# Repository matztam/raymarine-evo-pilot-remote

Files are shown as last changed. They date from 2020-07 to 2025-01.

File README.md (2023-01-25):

# Remote for Raymarine Evolution Autopilots

<table>
<tbody>
  <tr>
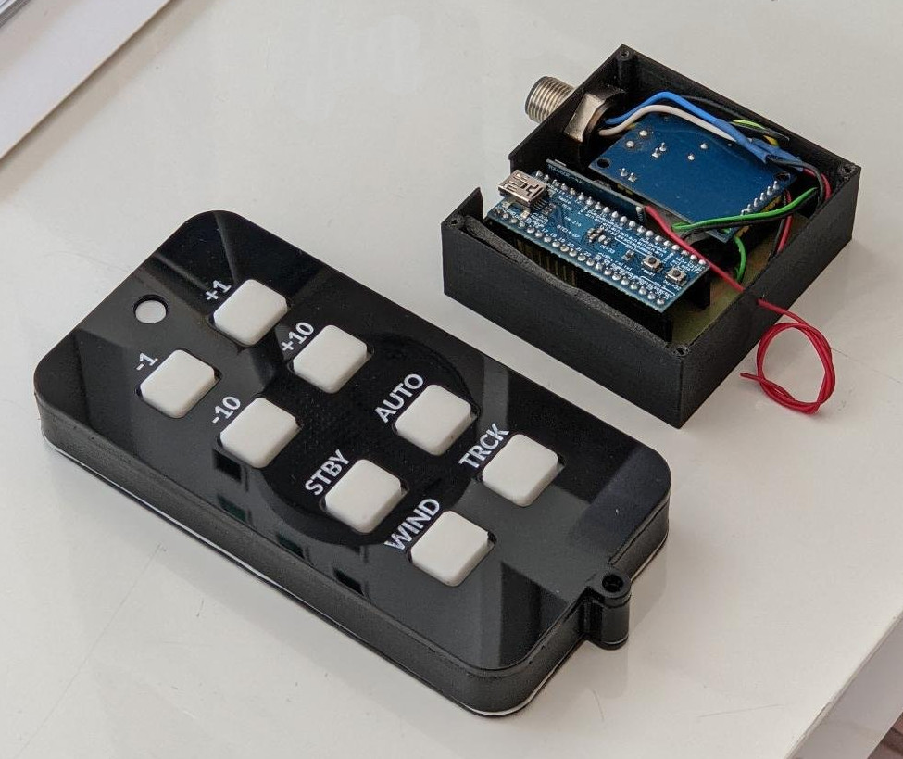
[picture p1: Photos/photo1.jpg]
    <td rowspan="2" valign="top"></td>
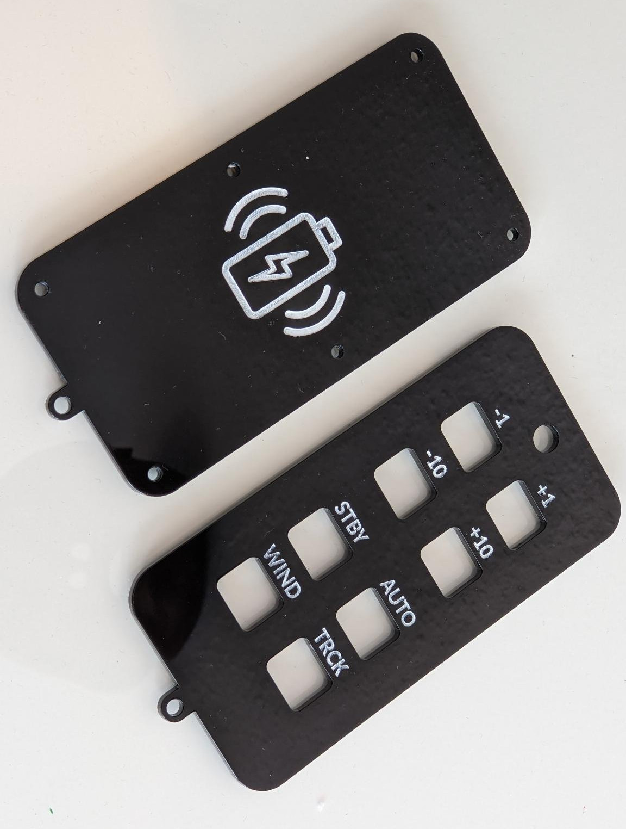
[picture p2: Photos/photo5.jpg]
    <td valign="top"></td>
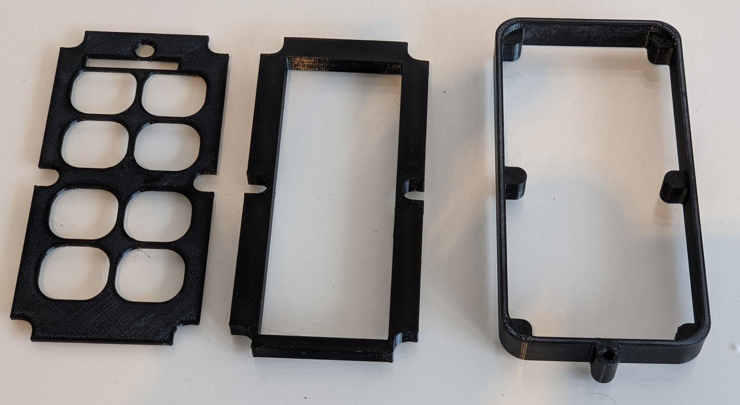
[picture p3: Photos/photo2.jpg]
    <td valign="bottom"></td>
  </tr>
  <tr>
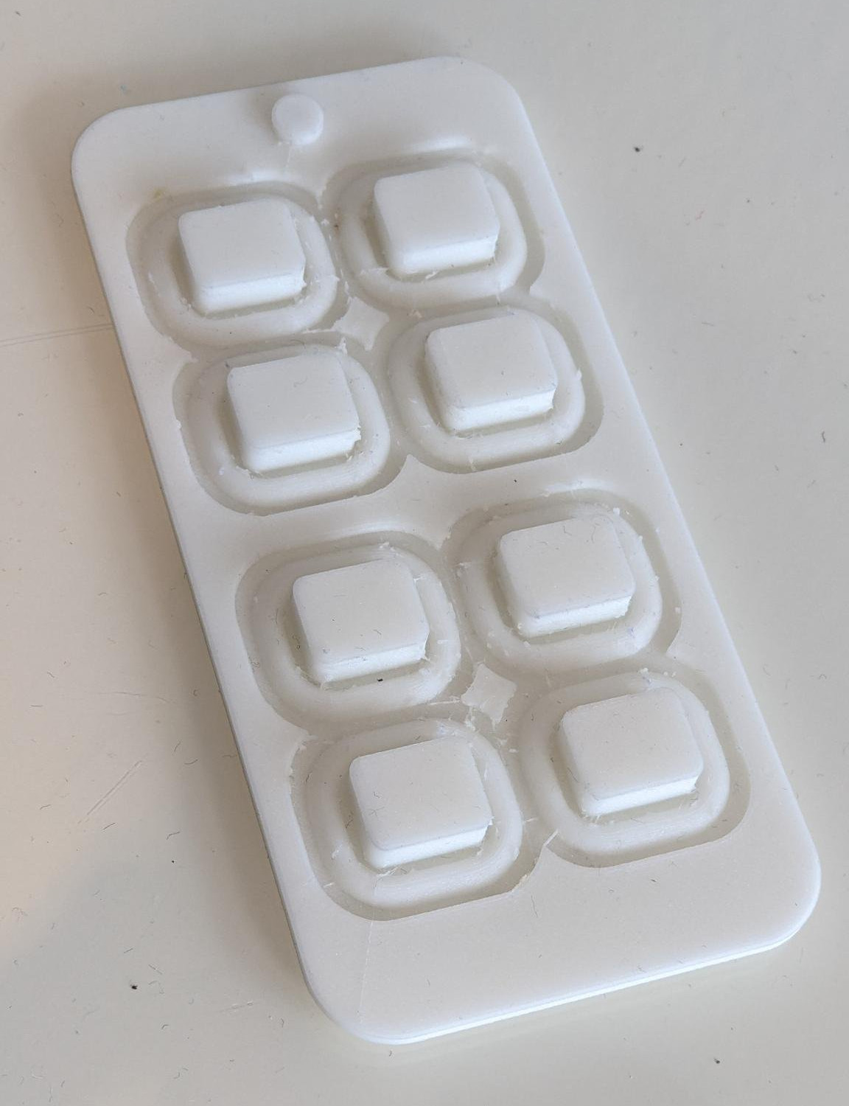
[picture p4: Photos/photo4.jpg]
    <td valign="top"></td>
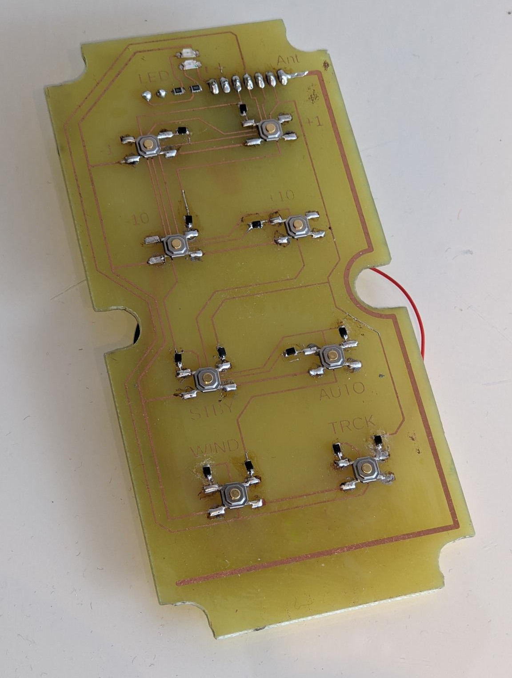
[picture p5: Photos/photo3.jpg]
    <td valign="top"></td>
  </tr>
</tbody>
</table>

## Libraries used:
* https://github.com/ttlappalainen/NMEA2000
* https://github.com/ttlappalainen/NMEA2000_mcp
* https://github.com/Seeed-Studio/CAN_BUS_Shield
* https://github.com/rogerclarkmelbourne/Arduino_STM32

## Hardware:

### Receiver
* Maple Mini (STM32F103) / Arduino_STM32
* MCP2551 CAN-BUS Module
* Logic Level Converter (https://www.sparkfun.com/products/12009)
* QIACHIP RX480E 433Mhz 4CH RF Receiver (https://qiachip.com/collections/all-products-1/products/qiachip-tx118sa-4-rx480e-kit-433-92mhz-wireless-wide-voltage-coding-transmitter-module-and-decoding-receiver-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)
* 12V to 5V step down converter

### Remote / Sender
* Qiachip TX118SA 433Mhz 4CH RF Transmitter (https://qiachip.com/collections/all-products-1/products/qiachip-tx118sa-4-rx480e-kit-433-92mhz-wireless-wide-voltage-coding-transmitter-module-and-decoding-receiver-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)
* Qi wireless charging receiver coil (https://www.aliexpress.com/item/32966646423.html)
* Lipo charger module
* Lipo battery 3.7V
* (Any Qi compatible charger)

### 3D print
keypad and seal were printed using TPE. The front and back were laser cut of acrylic (thanks to [@jliebers](https://github.com/jliebers)!). The remaining parts were printed using PETG. The front was glued to the frame using T7000

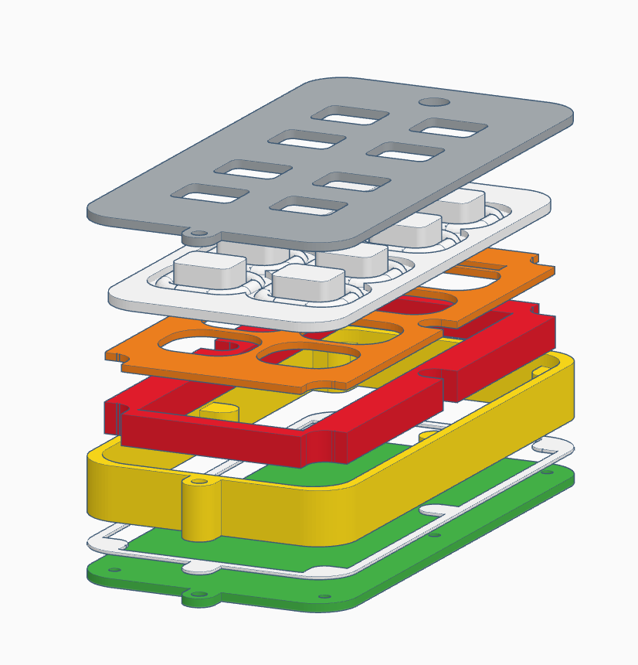
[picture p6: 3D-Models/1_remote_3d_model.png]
3d model


## Remote shortcuts

| Keys | Press and hold for one seconds | Description |
|---|---|---|
| +1 & +10 | 1 | Tack starboard |
| -1 & -10 | 1 | Tack portside |
| +1 & Wind | 1 | Key lock |
| Standby & Auto | 2 | Set target wind angle to 0° |

## Commands via tty
| input | Description |
| ----- | --- |
| s | Standby |
| a | Auto (course) mode |
| w | Wind Vane mode |
| t | Track mode |
| + | Plus 10 degrees |
| - | Minus 10 degrees |
| c | Confirm Waypoint advance |
| 1 | Key +1 |
| 2 | Key +10 |
| 3 | Key -1 |
| 4 | Key -10 |
| 5 | Keys -1 and -10 pressed simultaneously |
| 6 | Keys +1 and +10 pressed simultaneously |

## Board

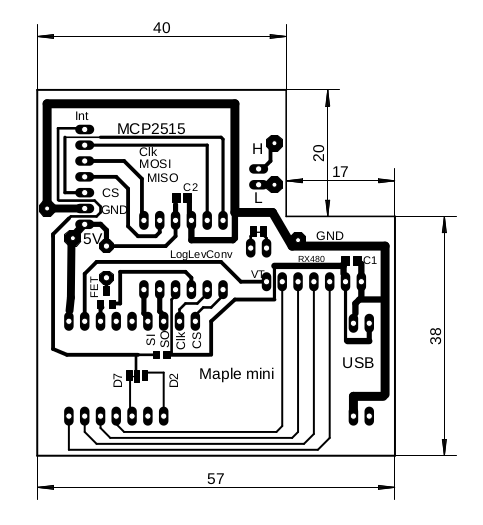
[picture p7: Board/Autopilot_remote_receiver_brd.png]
board receiver

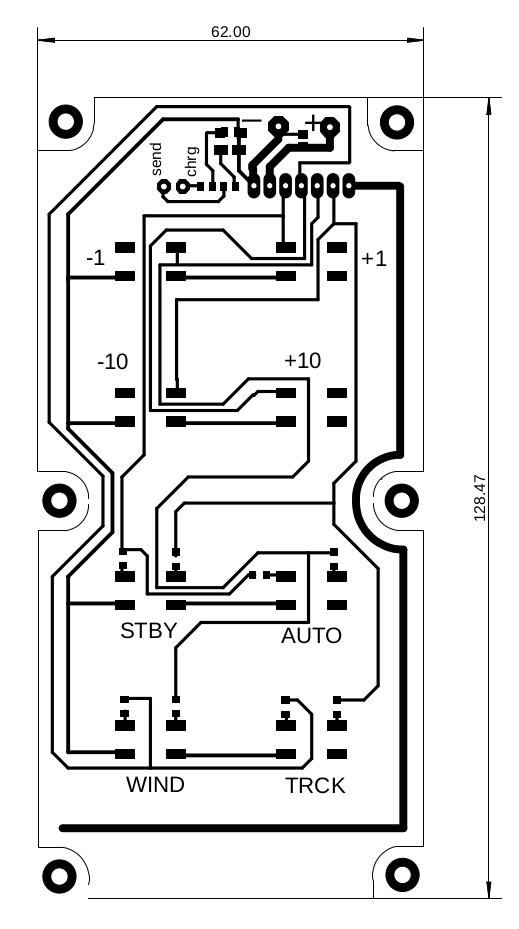
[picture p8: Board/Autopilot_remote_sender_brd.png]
board sender


## Schematic

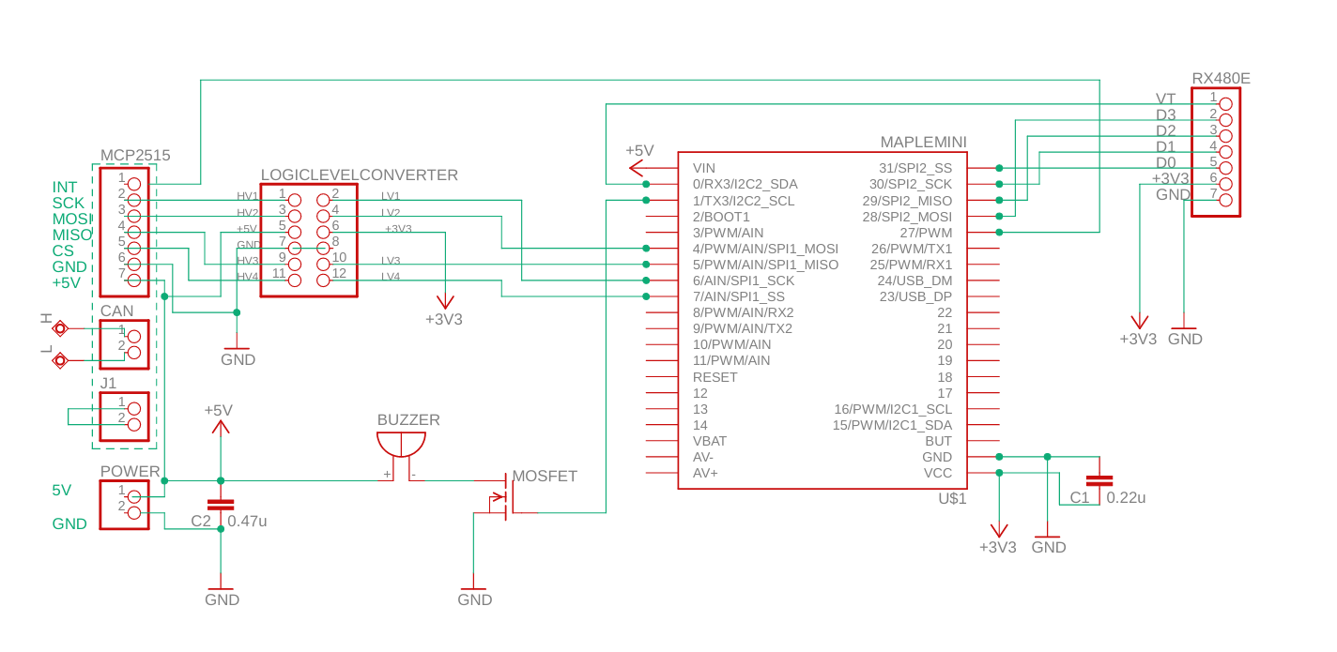
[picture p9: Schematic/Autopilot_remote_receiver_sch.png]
schematic receiver

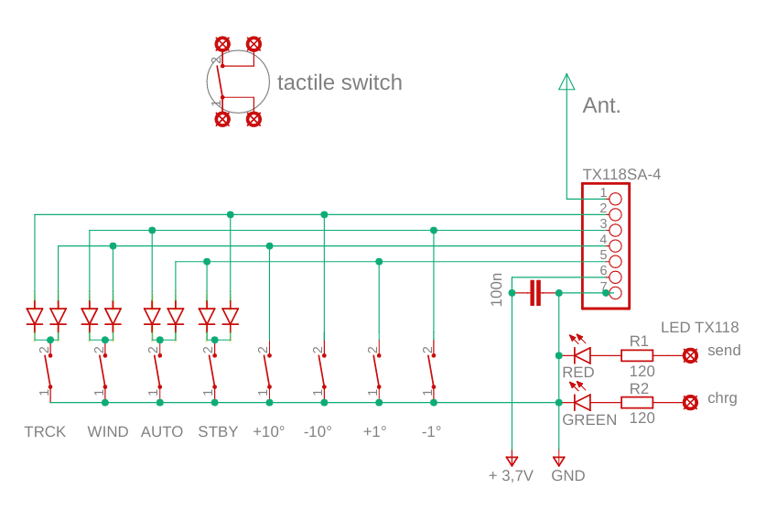
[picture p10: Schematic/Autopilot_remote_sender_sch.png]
schematic sender


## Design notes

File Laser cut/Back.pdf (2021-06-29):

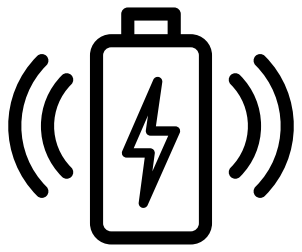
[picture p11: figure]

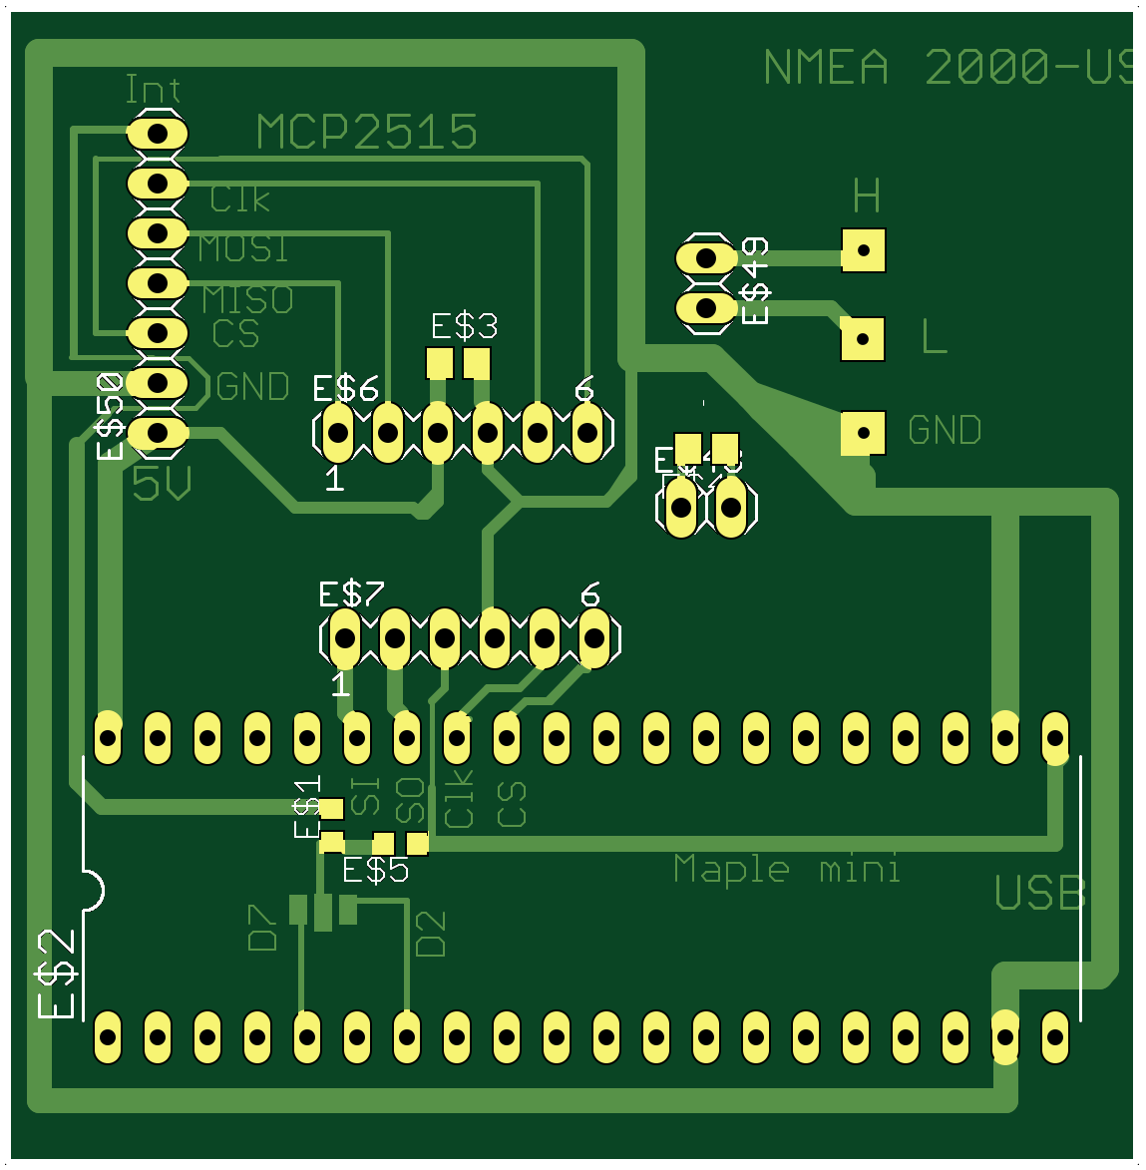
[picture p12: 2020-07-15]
Board/NMEA2000_USB_topview.png

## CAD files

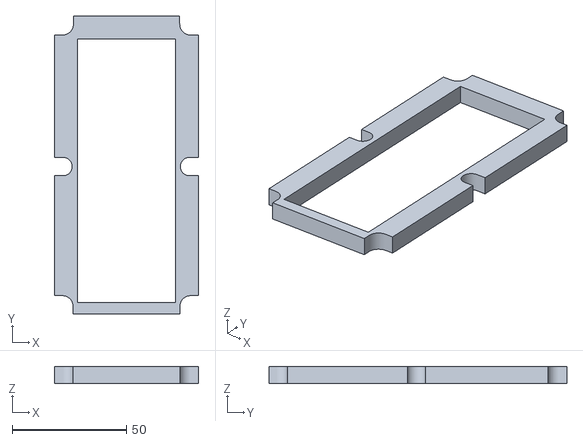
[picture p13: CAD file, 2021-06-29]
3D-Models/Inner frame.stl
63.0 x 130.2 x 7.50

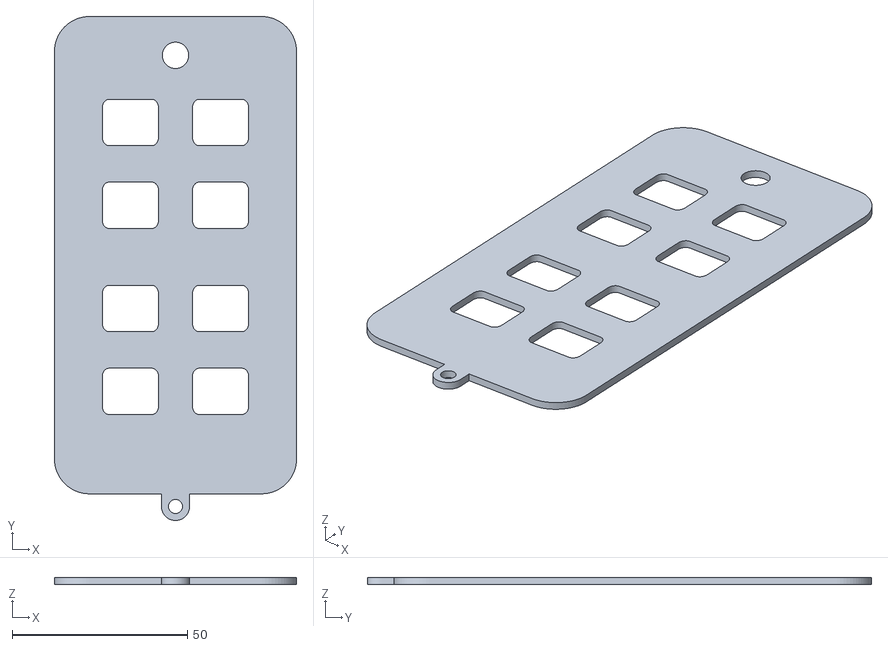
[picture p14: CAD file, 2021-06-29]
3D-Models/Front.stl
69.0 x 143.6 x 2.00

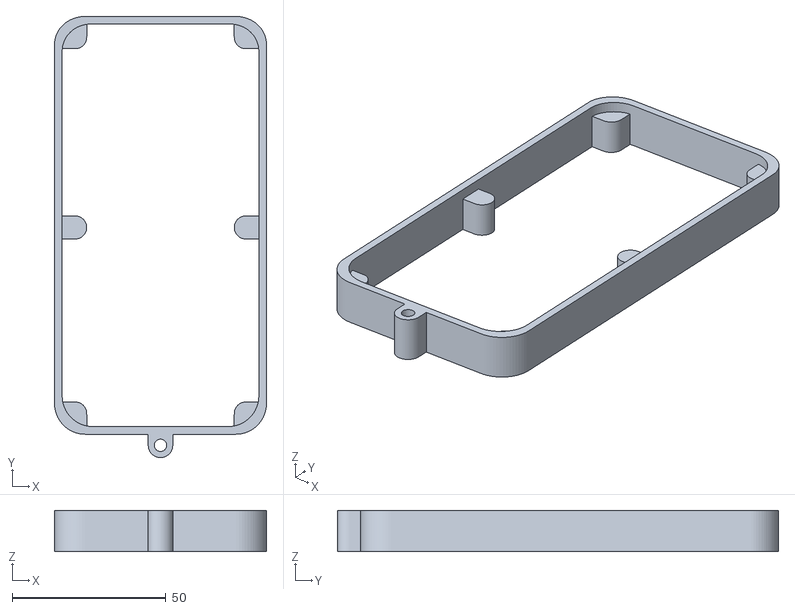
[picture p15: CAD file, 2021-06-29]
3D-Models/Outer frame.stl
69.0 x 143.6 x 13.5

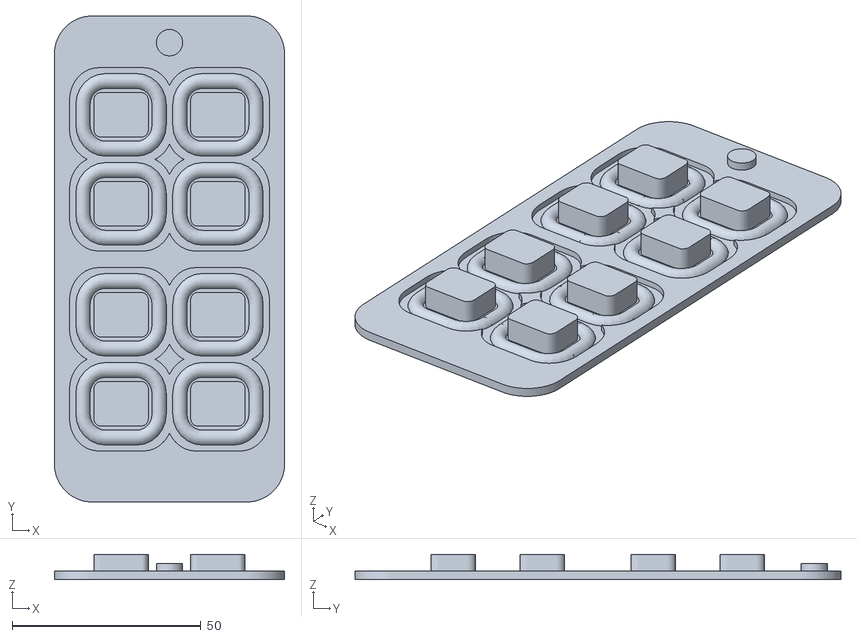
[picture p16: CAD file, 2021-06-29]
3D-Models/Key pad.stl
61.0 x 128.8 x 6.72

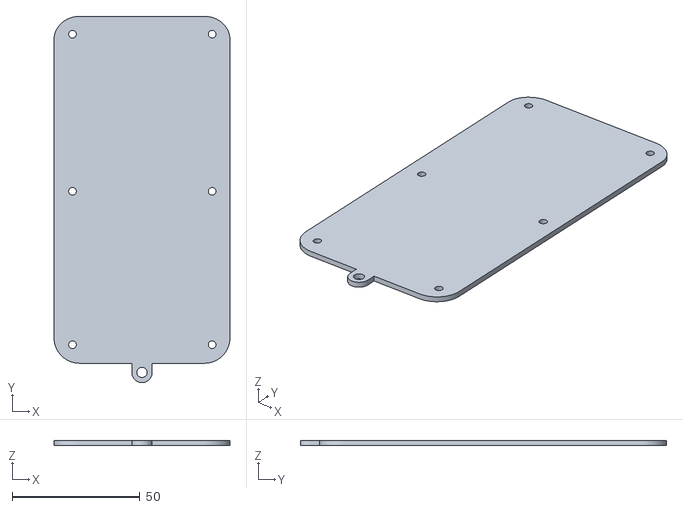
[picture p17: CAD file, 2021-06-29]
3D-Models/Back.stl
69.0 x 143.6 x 2.00

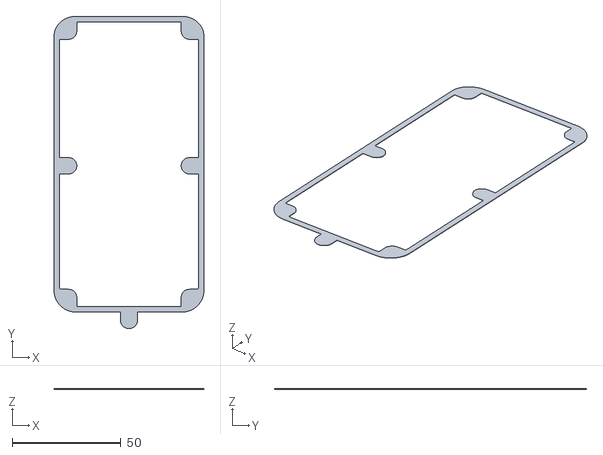
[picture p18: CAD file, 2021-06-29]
3D-Models/Seal.stl
69.0 x 143.6 x 0.5

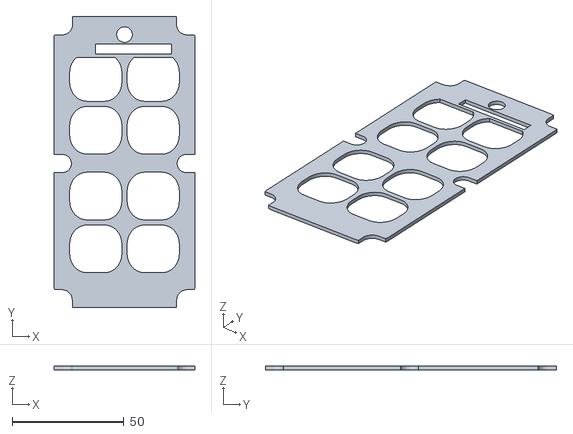
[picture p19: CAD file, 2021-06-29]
3D-Models/Placeholder.stl
63.0 x 130.2 x 1.60

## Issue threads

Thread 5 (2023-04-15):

Gerber

m-feddersen, 2023-04-15:
Hello Matztam,
I fail to create the Gerber file. I can't do that with Fusion 360 and Kicad. Can you add the finished Gerber file to your package, or give me a tip how to create it from the schematic?
With kind regards
Matze

matztam, 2025-01-13:
Hi Matze,
Sorry, it took a while. Here are the Gerber files:: https://github.com/matztam/raymarine-evo-pilot-remote/tree/master/Board/Gerber

Closed 2025-01-13.

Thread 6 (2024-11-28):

EvoPilotremote.ino.elf section `.text' will not fit in region `FLASH'

syntacrsc, 2024-11-28:
Hello.

While trying to verify the .ino code I get the error below - looks like the "Genric STM32F1" series board does not have enough space for the build?

I've already tried to disable some of the HAL Modules via hal_conf_extra.h
```
#define HAL_ADC_MODULE_DISABLED
#define HAL_I2C_MODULE_DISABLED
#define HAL_RTC_MODULE_DISABLED
//#define HAL_SPI_MODULE_DISABLED
#define HAL_TIM_MODULE_DISABLED
```
This reduced the size a little but not enough to fit.

Just for curiousity sake I tried "Genric STM32F2 series" board - that compiles correctly (but I'm not sure what will happen when I'd try to flush to a STM32F1 series board).

My IDE ist Arduino IDE 2.3.3.

What am I doing wrong?

Any help is highly appreciated!

Thanks and kind regards,
Ralph...

P.S.:
This is the error message I'm getting:

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

matztam, 2025-01-09:
Please select the board "Maple Mini"

Closed 2025-01-13.

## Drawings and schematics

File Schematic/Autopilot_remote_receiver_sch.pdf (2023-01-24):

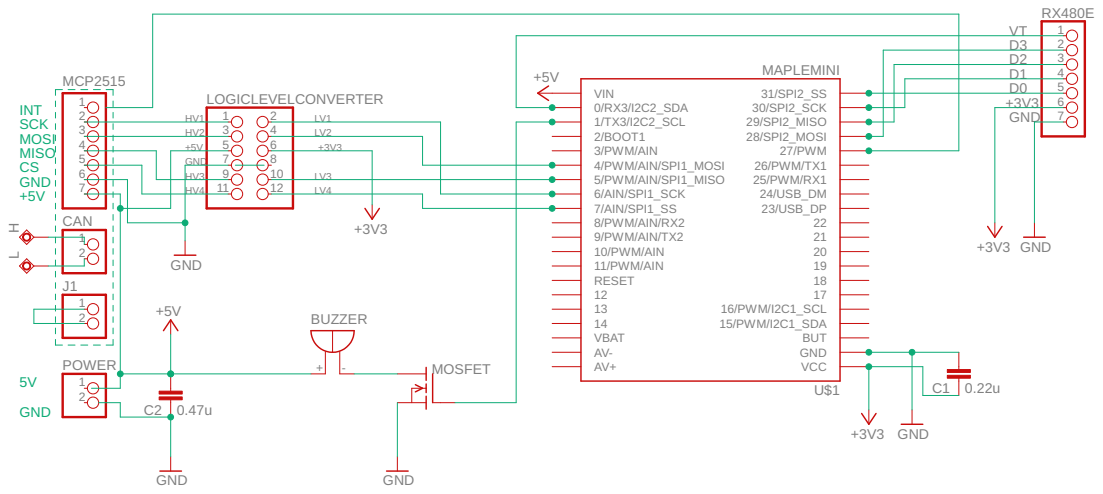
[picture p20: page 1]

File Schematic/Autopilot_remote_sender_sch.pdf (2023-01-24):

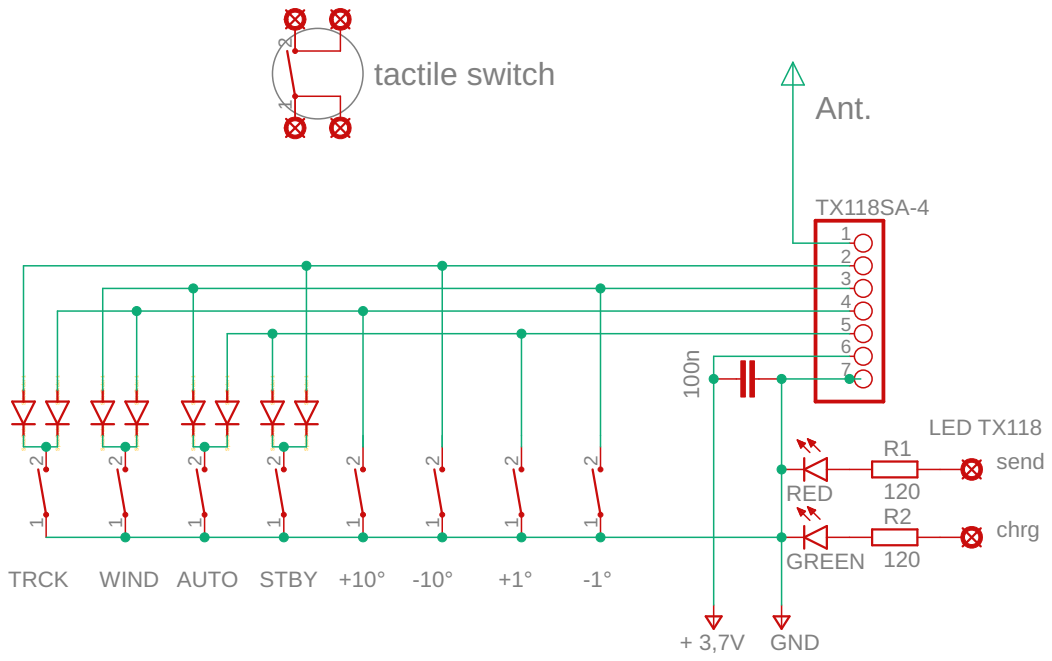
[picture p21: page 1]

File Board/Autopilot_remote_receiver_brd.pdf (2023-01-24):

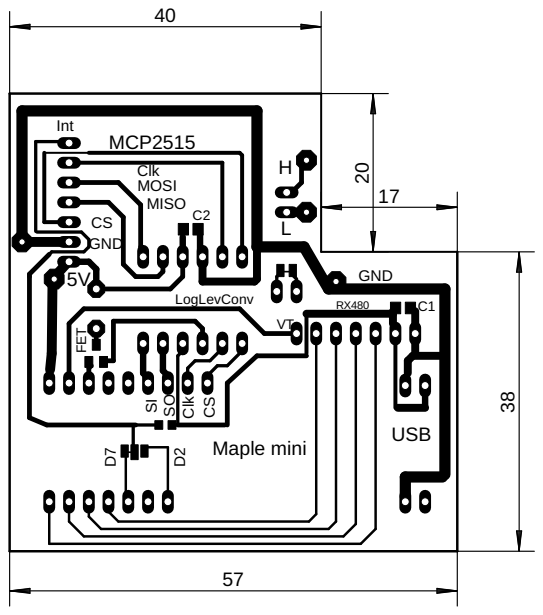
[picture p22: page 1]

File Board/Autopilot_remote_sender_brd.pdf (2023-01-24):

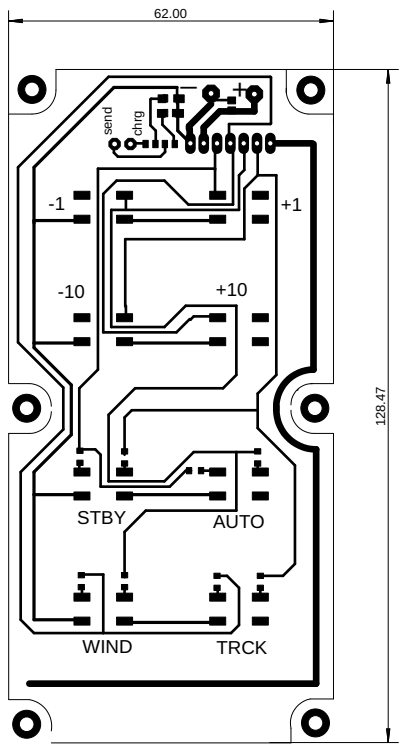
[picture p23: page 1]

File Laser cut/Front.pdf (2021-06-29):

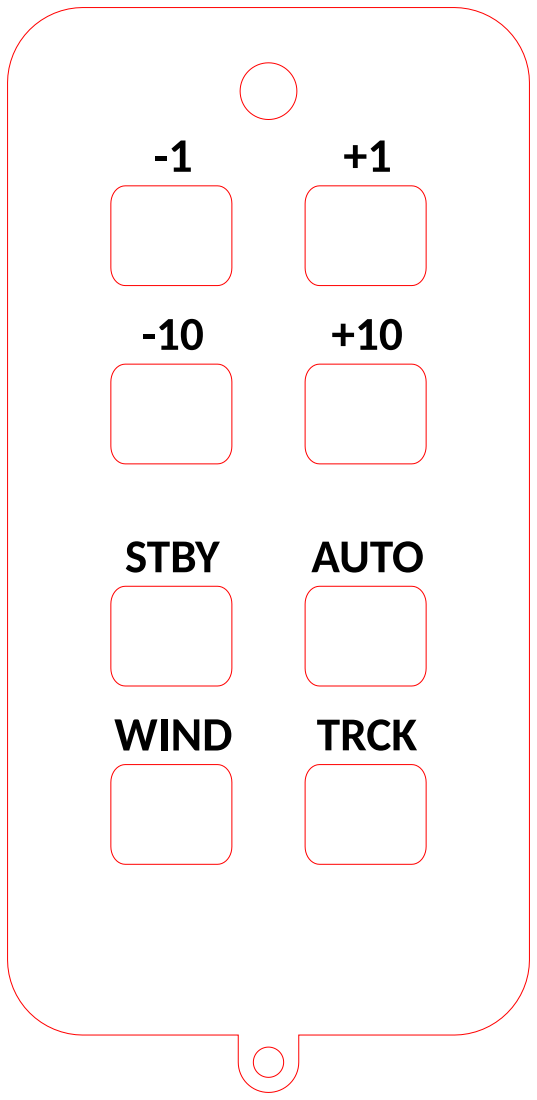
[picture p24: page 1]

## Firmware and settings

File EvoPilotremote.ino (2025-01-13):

#define DEBUG

#ifdef DEBUG
#define DEBUG_PRINT(x) Serial.print(x)
#define DEBUG_PRINTLN(x) Serial.println(x)
#define DEBUG_PRINTLNFMT(x,y) Serial.println(x,y)
#else
#define DEBUG_PRINT(x)
#define DEBUG_PRINTLN(x)
#define DEBUG_PRINTLNFMT(x,y)
#endif

#define KEYLOCK_TIMEOUT_MS 1000
#define TACK_TIMEOUT_MS 1000
#define HEADING_WIND_TIMEOUT_MS 2000

#define INPUT_ADJUST_HEADING_PLUS_1       4   //0100
#define INPUT_ADJUST_HEADING_PLUS_10      8   //1000
#define INPUT_ADJUST_HEADING_MINUS_1      2   //0010
#define INPUT_ADJUST_HEADING_MINUS_10     1   //0001
#define INPUT_ADJUST_HEADING_AGAINST_WIND 7   //0111
#define INPUT_TACK_STARBOARD              12  //1100
#define INPUT_TACK_PORT                   3   //0011
#define INPUT_STATE_AUTO                  6   //0110
#define INPUT_STATE_WIND                  10  //1010
#define INPUT_STATE_STANDBY               5   //0101
#define INPUT_STATE_ROUTE                 9   //1011
#define INPUT_KEYLOCK                     14  //1110

#define pinBuzzer PB10
#define pinVT     PB11
#define pinD0     PB12
#define pinD1     PB13
#define pinD2     PB14
#define pinD3     PB15

#define USE_N2K_CAN 1

#define N2k_SPI_CS_PIN 7
#define N2k_CAN_INT_PIN 27
#define USE_MCP_CAN_CLOCK_SET 8  // possible values 8 for 8Mhz and 16 for 16 Mhz clock

#include <Arduino.h>
#include <N2kMsg.h>
#include <NMEA2000.h>
#include <NMEA2000_CAN.h>

#include "RaymarinePilot.h"
#include "N2kDeviceList.h"
#include <libmaple/iwdg.h>

const unsigned long TransmitMessages[] PROGMEM={126208UL,0};
const unsigned long ReceiveMessages[] PROGMEM={127250L,65288L,65379L,0};

tN2kDeviceList *pN2kDeviceList;

byte inByte;

bool keylockEnabled = true;

long keylockTimeout = 0;
long tackTimeout = 0;
long headingToWindTimeout = 0;
long beepTimeout = 0;

unsigned short* beepPattern;
int beepPatternIndex = 0;

unsigned short BEEP_NULL[] = {0};
unsigned short BEEP_SINGLE_BUTTON[] = {100, 0};
unsigned short BEEP_KEYLOCK_ENABLE[] = {150, 50, 150, 50, 150, 0};
unsigned short BEEP_KEYLOCK_DISABLE[] = {150, 50, 150, 0};
unsigned short BEEP_TACK[] = {1000, 0};
unsigned short BEEP_HEADING_AGAINST_WIND[] = {1000, 200, 1000, 0};
unsigned short BEEP_STARTUP[] = {300, 0};

void setup() {
  iwdg_init(IWDG_PRE_256, 3000); // init an 16+ second wd timer
  pinMode(pinBuzzer, OUTPUT);
  digitalWrite(pinBuzzer, 0);
  pinMode(pinVT, INPUT);
  pinMode(pinD0, INPUT);
  pinMode(pinD1, INPUT);
  pinMode(pinD2, INPUT);
  pinMode(pinD3, INPUT);

  attachInterrupt(digitalPinToInterrupt(pinVT), handleRemoteInput, RISING);

  // Reserve enough buffer for sending all messages. This does not work on small memory devices like Uno or Mega
  NMEA2000.SetN2kCANReceiveFrameBufSize(150);
  NMEA2000.SetN2kCANMsgBufSize(8);
  // Set Product information
  NMEA2000.SetProductInformation("00000001", // Manufacturer's Model serial code
                                 100, // Manufacturer's product code
                                 "Evo Pilot Remote",  // Manufacturer's Model ID
                                 "1.0.0.0",  // Manufacturer's Software version code
                                 "1.0.0.0" // Manufacturer's Model version
                                );
  // Set device information
  NMEA2000.SetDeviceInformation(1111, // Unique number. Use e.g. Serial number.
                                132, // Device function=Analog to NMEA 2000 Gateway. See codes on http://www.nmea.org/Assets/20120726%20nmea%202000%20class%20&%20function%20codes%20v%202.00.pdf
                                25, // Device class=Inter/Intranetwork Device. See codes on  http://www.nmea.org/Assets/20120726%20nmea%202000%20class%20&%20function%20codes%20v%202.00.pdf
                                2046 // Just choosen free from code list on http://www.nmea.org/Assets/20121020%20nmea%202000%20registration%20list.pdf
                               );
  Serial.begin(115200);
  delay(100);

  #ifdef DEBUG
  NMEA2000.SetForwardStream(&Serial);  // PC output on due programming port
  NMEA2000.SetForwardType(tNMEA2000::fwdt_Text); // Show in clear text. Leave uncommented for default Actisense format.
  NMEA2000.SetForwardOwnMessages();
  #endif

  // If you also want to see all traffic on the bus use N2km_ListenAndNode instead of N2km_NodeOnly below
  NMEA2000.SetMode(tNMEA2000::N2km_NodeOnly, 51); //N2km_NodeOnly N2km_ListenAndNode
  NMEA2000.ExtendTransmitMessages(TransmitMessages);
  NMEA2000.ExtendReceiveMessages(ReceiveMessages);

  NMEA2000.SetMsgHandler(RaymarinePilot::HandleNMEA2000Msg);

  
  pN2kDeviceList = new tN2kDeviceList(&NMEA2000);
  #ifdef DEBUG
  NMEA2000.EnableForward(true);
  #endif
  NMEA2000.Open();

  unsigned long t = millis();
  
  while(RaymarinePilot::PilotSourceAddress < 0 && millis() - t < 5000){
    iwdg_feed();
    NMEA2000.ParseMessages();
    RaymarinePilot::PilotSourceAddress = getDeviceSourceAddress("EV-1");
    delay(50);
  }

  if(RaymarinePilot::PilotSourceAddress >= 0){
    Serial.println((String) "Found EV-1 Pilot: " + RaymarinePilot::PilotSourceAddress);
  }else{
    RaymarinePilot::PilotSourceAddress = 204;
    Serial.println((String) "EV-1 Pilot not found. Defaulting to " + RaymarinePilot::PilotSourceAddress);
  }

  beep(BEEP_STARTUP);
  iwdg_init(IWDG_PRE_256, 1250); // set watchdog timer to 8 seconds
}

void loop() {
  iwdg_feed();
  handleTimers();  
  
  if (Serial.available() > 0) {
    inByte = Serial.read();

    if (inByte == 's') {
      Serial.println("Setting PILOT_MODE_STANDBY");
      
      tN2kMsg N2kMsg;
      RaymarinePilot::SetEvoPilotMode(N2kMsg, PILOT_MODE_STANDBY);
      NMEA2000.SendMsg(N2kMsg);
    } 
    
    else if (inByte == 'a') {
      Serial.println("Setting PILOT_MODE_AUTO");
      
      tN2kMsg N2kMsg;
      RaymarinePilot::SetEvoPilotMode(N2kMsg, PILOT_MODE_AUTO);
      NMEA2000.SendMsg(N2kMsg);
    } 
    
    else if (inByte == 'w') {
      Serial.println("Setting PILOT_MODE_WIND");
      
      tN2kMsg N2kMsg;
      RaymarinePilot::SetEvoPilotMode(N2kMsg, PILOT_MODE_WIND);
      NMEA2000.SendMsg(N2kMsg);
    } 
    
    else if (inByte == 't') {
      Serial.println("Setting PILOT_MODE_TRACK");
      
      tN2kMsg N2kMsg;
      RaymarinePilot::SetEvoPilotMode(N2kMsg, PILOT_MODE_TRACK);
      NMEA2000.SendMsg(N2kMsg);
    }
    
    else if (inByte == '+') {
      Serial.print("Setting course to ");
      Serial.println((((int) RaymarinePilot::Heading + 10) % 360));
      
      tN2kMsg N2kMsg;
      RaymarinePilot::SetEvoPilotCourse(N2kMsg, RaymarinePilot::Heading, 10);
      NMEA2000.SendMsg(N2kMsg);
    }
    
    else if (inByte == '-') {
      Serial.print("Setting course to ");
      Serial.println((((int) RaymarinePilot::Heading - 10 + 360) % 360));
      
      tN2kMsg N2kMsg;
      RaymarinePilot::SetEvoPilotCourse(N2kMsg, RaymarinePilot::Heading, -10);
      NMEA2000.SendMsg(N2kMsg);
    }

    else if(inByte == 'c'){
        Serial.println("Confirm Waypoint");
      
        tN2kMsg N2kMsg1;
        RaymarinePilot::TurnToWaypointMode(N2kMsg1);
        NMEA2000.SendMsg(N2kMsg1);

        tN2kMsg N2kMsg2;
        RaymarinePilot::TurnToWaypoint(N2kMsg2);
        NMEA2000.SendMsg(N2kMsg2);
    }

    else if(inByte == '1'){
        Serial.println("Plus 1");
      
        tN2kMsg N2kMsg;
        RaymarinePilot::KeyCommand(N2kMsg, KEY_PLUS_1);
        NMEA2000.SendMsg(N2kMsg);
    }

    else if(inByte == '2'){
        Serial.println("Plus 10");
      
        tN2kMsg N2kMsg;
        RaymarinePilot::KeyCommand(N2kMsg, KEY_PLUS_10);
        NMEA2000.SendMsg(N2kMsg);
    }

    else if(inByte == '3'){
        Serial.println("Minus 1");
      
        tN2kMsg N2kMsg;
        RaymarinePilot::KeyCommand(N2kMsg, KEY_MINUS_1);
        NMEA2000.SendMsg(N2kMsg);
    }

    else if(inByte == '4'){
        Serial.println("Minus 10");
      
        tN2kMsg N2kMsg;
        RaymarinePilot::KeyCommand(N2kMsg, KEY_MINUS_10);
        NMEA2000.SendMsg(N2kMsg);
    }

    else if(inByte == '5'){
        Serial.println("Minus 1 Minus 10");
      
        tN2kMsg N2kMsg;
        RaymarinePilot::KeyCommand(N2kMsg, KEY_MINUS_1_MINUS_10);
        NMEA2000.SendMsg(N2kMsg);
    }

    else if(inByte == '6'){
        Serial.println("Plus 1 Plus 10");
      
        tN2kMsg N2kMsg;
        RaymarinePilot::KeyCommand(N2kMsg, KEY_PLUS_1_PLUS_10);
        NMEA2000.SendMsg(N2kMsg);
    }
  }

  if(RaymarinePilot::alarmWaypoint){
    Serial.println("Confirm Waypoint");
      
    tN2kMsg N2kMsg1;
    RaymarinePilot::TurnToWaypointMode(N2kMsg1);
    NMEA2000.SendMsg(N2kMsg1);

    tN2kMsg N2kMsg2;
    RaymarinePilot::TurnToWaypoint(N2kMsg2);
    NMEA2000.SendMsg(N2kMsg2);

    RaymarinePilot::alarmWaypoint = false;
  }

  NMEA2000.ParseMessages();  
}

void handleTimers(){
  if(keylockTimeout > 0 && keylockTimeout < millis()){
    handleRemoteInput();
    keylockTimeout = 0;
  }

  if(tackTimeout > 0 && tackTimeout < millis()){
    handleRemoteInput();
    tackTimeout = 0;
  }

  if(headingToWindTimeout > 0 && headingToWindTimeout < millis()){
    handleRemoteInput();
    headingToWindTimeout = 0;
  }

  if(beepTimeout > 0 && beepTimeout < millis()){
    beep(BEEP_NULL);
  }
}

void handleRemoteInput(){
  delay(100);
  
  byte input = readInput();

  if(keylockEnabled && input != INPUT_KEYLOCK){
    beep(BEEP_KEYLOCK_ENABLE);
    return;
  }

  tN2kMsg N2kMsg;

  switch (input) {
    case INPUT_KEYLOCK:
      if(keylockTimeout > 0 && keylockTimeout < millis()){
        keylockEnabled ^= true;
        
        if(keylockEnabled){
          beep(BEEP_KEYLOCK_ENABLE);
        }else{
          beep(BEEP_KEYLOCK_DISABLE);
        }
        
        return;
      }
      keylockTimeout = millis() + KEYLOCK_TIMEOUT_MS;
      return;
      
    case INPUT_ADJUST_HEADING_PLUS_1:
      RaymarinePilot::KeyCommand(N2kMsg, KEY_PLUS_1);
      DEBUG_PRINTLN("INPUT_ADJUST_HEADING_PLUS_1");
      beep(BEEP_SINGLE_BUTTON);
      break;
      
    case INPUT_ADJUST_HEADING_PLUS_10:
      RaymarinePilot::KeyCommand(N2kMsg, KEY_PLUS_10);
      DEBUG_PRINTLN("INPUT_ADJUST_HEADING_PLUS_10");
      beep(BEEP_SINGLE_BUTTON);
      break;
      
    case INPUT_ADJUST_HEADING_MINUS_1:
      RaymarinePilot::KeyCommand(N2kMsg, KEY_MINUS_1);
      DEBUG_PRINTLN("INPUT_ADJUST_HEADING_MINUS_1");
      beep(BEEP_SINGLE_BUTTON);
      break;
      
    case INPUT_ADJUST_HEADING_MINUS_10:
      RaymarinePilot::KeyCommand(N2kMsg, KEY_MINUS_10);
      DEBUG_PRINTLN("INPUT_ADJUST_HEADING_MINUS_10");
      beep(BEEP_SINGLE_BUTTON);
      break;
      
    case INPUT_ADJUST_HEADING_AGAINST_WIND:
      if(headingToWindTimeout == 0 || headingToWindTimeout > millis()){
        headingToWindTimeout = millis() + HEADING_WIND_TIMEOUT_MS;
        return;
      }
      RaymarinePilot::SetEvoPilotWind(N2kMsg, 0);
      DEBUG_PRINTLN("INPUT_ADJUST_HEADING_AGAINST_WIND");
      beep(BEEP_HEADING_AGAINST_WIND);
      break;
      
    case INPUT_TACK_STARBOARD:
      if(tackTimeout == 0 || tackTimeout > millis()){
        tackTimeout = millis() + TACK_TIMEOUT_MS;
        return;
      }
      RaymarinePilot::KeyCommand(N2kMsg, KEY_PLUS_1_PLUS_10);
      DEBUG_PRINTLN("INPUT_TACK_STARBOARD");
      beep(BEEP_TACK);
      break;
      
    case INPUT_TACK_PORT:
      if(tackTimeout == 0 || tackTimeout > millis()){
        tackTimeout = millis() + TACK_TIMEOUT_MS;
        return;
      }
      RaymarinePilot::KeyCommand(N2kMsg, KEY_MINUS_1_MINUS_10);
      DEBUG_PRINTLN("INPUT_TACK_PORT");
      beep(BEEP_TACK);
      break;
      
    case INPUT_STATE_AUTO:
      RaymarinePilot::SetEvoPilotMode(N2kMsg, PILOT_MODE_AUTO);
      DEBUG_PRINTLN("INPUT_STATE_AUTO");
      beep(BEEP_SINGLE_BUTTON);
      break;
      
    case INPUT_STATE_WIND:
      RaymarinePilot::SetEvoPilotMode(N2kMsg, PILOT_MODE_WIND);
      DEBUG_PRINTLN("INPUT_STATE_WIND");
      beep(BEEP_SINGLE_BUTTON);
      break;
      
    case INPUT_STATE_STANDBY:
      RaymarinePilot::SetEvoPilotMode(N2kMsg, PILOT_MODE_STANDBY);
      DEBUG_PRINTLN("INPUT_STATE_STANDBY");
      beep(BEEP_SINGLE_BUTTON);
      break;
      
    case INPUT_STATE_ROUTE:
      RaymarinePilot::SetEvoPilotMode(N2kMsg, PILOT_MODE_TRACK);
      DEBUG_PRINTLN("INPUT_STATE_ROUTE");
      beep(BEEP_SINGLE_BUTTON);
      break;
      
    default: 
      return; //do nothing
      break;
  }

  NMEA2000.SendMsg(N2kMsg);
  
}

byte readInput(){
  byte input = 0;

  input |= digitalRead(pinD0);
  input |= digitalRead(pinD1) << 1;
  input |= digitalRead(pinD2) << 2;
  input |= digitalRead(pinD3) << 3;

  DEBUG_PRINT("input :");
  DEBUG_PRINTLNFMT(input, BIN);
  return input;
}

void beep(unsigned short pattern[]){
  if(pattern[0] != 0){
    beepPattern = pattern;
    beepPatternIndex = 0;
    digitalWrite(pinBuzzer, 0);
  }
  if(beepPattern[beepPatternIndex] == 0){
    beepPatternIndex = 0;
    beepTimeout = 0;
    digitalWrite(pinBuzzer, 0);
    return;
  }
  digitalWrite(pinBuzzer, !digitalRead(pinBuzzer));  
  beepTimeout = beepPattern[beepPatternIndex] + millis();
  beepPatternIndex++;  
}

int getDeviceSourceAddress(String model) {
  if (!pN2kDeviceList->ReadResetIsListUpdated()) return -1;

  for (uint8_t i = 0; i < N2kMaxBusDevices; i++){ 
    const tNMEA2000::tDevice *device=pN2kDeviceList->FindDeviceBySource(i);
    if ( device == 0 ) continue;
    
    String modelVersion = device->GetModelVersion();
    
    if(modelVersion.indexOf(model) >= 0){
      return device->GetSource();
    }
  }

  return -2;
}

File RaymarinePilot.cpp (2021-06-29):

#include "RaymarinePilot.h"
#include <string.h>

double RaymarinePilot::Heading = 0;
double RaymarinePilot::Variation = 0;
int RaymarinePilot::PilotSourceAddress = -1;
uint8_t RaymarinePilot::PilotMode = PILOT_MODE_STANDBY;
unsigned int pilotHeadingFilterCount = 0;

bool RaymarinePilot::alarmWaypoint = false;

//PilotSourceAddress muss aus der tN2kDeviceList ausgelesen werden. Beispiel dazu: DeviceAnalyzer.ino

void RaymarinePilot::SetEvoPilotMode(tN2kMsg &N2kMsg,RaymarinePilotModes mode) {
  N2kMsg.SetPGN(126208UL);
  N2kMsg.Priority=3;
  N2kMsg.Destination=PilotSourceAddress;
  N2kMsg.AddByte(1); // Field 1, 1 = Command Message, 2 = Acknowledge Message...
  N2kMsg.AddByte(0x63);
  N2kMsg.AddByte(0xff);
  N2kMsg.AddByte(0x00);
  N2kMsg.AddByte(0xf8);
  N2kMsg.AddByte(0x04);
  N2kMsg.AddByte(0x01);
  N2kMsg.AddByte(0x3b);
  N2kMsg.AddByte(0x07);
  N2kMsg.AddByte(0x03);
  N2kMsg.AddByte(0x04);
  N2kMsg.AddByte(0x04);

  // 0x00 = standby, 0x40 = auto, 0x0100=vane, 0x0180=track
  switch (mode) {
  case PILOT_MODE_STANDBY:
    N2kMsg.AddByte(0x00);
    N2kMsg.AddByte(0x00);
    break;
  case PILOT_MODE_AUTO:
    N2kMsg.AddByte(0x40);
    N2kMsg.AddByte(0x00);
    break;
  case PILOT_MODE_WIND:
    N2kMsg.AddByte(0x00);
    N2kMsg.AddByte(0x01);
    break;
  case PILOT_MODE_TRACK:
    N2kMsg.AddByte(0x80);
    N2kMsg.AddByte(0x01);
    break;   
  }
 
  N2kMsg.AddByte(0x05);
  N2kMsg.AddByte(0xff);
  N2kMsg.AddByte(0xff);

  /*N2kMsg.Add3ByteInt(126208UL); // Field 2, commanded PGN 3 byte,  LSB is transmitted first  
  N2kMsg.AddByte(0xf0 | 0x8 ); // Field 3, 0x8 = Do not change priority and field 4 is nmea reserved
  N2kMsg.AddByte(1); // Field 5, 1 field/value pair
  N2kMsg.AddByte(4); // Field 6, field 4 to be commanded
  N2kMsg.Add4ByteUInt(0); // Field 7, value for first pair =0 for reset distance log.*/
}

void RaymarinePilot::SetEvoPilotCourse(tN2kMsg &N2kMsg,double heading, int change) {
  double course = heading + change;
  if ((course) >= 360){
    course -= 360;
  } else if ((course) < 0){
    course += 360;
  }
  
  uint16_t courseRadials10000 = (uint16_t) (DegToRad(course) * 10000); //(newCourse * 174.53); 

  byte byte0, byte1;
  byte0 = courseRadials10000 & 0xff;
  byte1 = courseRadials10000 >> 8;

  //01,50,ff,00,f8,03,01,3b,07,03,04,06,00,00
  
  N2kMsg.SetPGN(126208UL);
  N2kMsg.Priority=3;
  N2kMsg.Destination=PilotSourceAddress;
  N2kMsg.AddByte(1); // Field 1, 1 = Command Message, 2 = Acknowledge Message...
  N2kMsg.AddByte(0x50);
  N2kMsg.AddByte(0xff);
  N2kMsg.AddByte(0x00);
  N2kMsg.AddByte(0xf8);
  N2kMsg.AddByte(0x03);
  N2kMsg.AddByte(0x01);
  N2kMsg.AddByte(0x3b);
  N2kMsg.AddByte(0x07);
  N2kMsg.AddByte(0x03);
  N2kMsg.AddByte(0x04);
  N2kMsg.AddByte(0x06);
  N2kMsg.AddByte(byte0);
  N2kMsg.AddByte(byte1);
}

void RaymarinePilot::SetEvoPilotWind(tN2kMsg &N2kMsg, double targetWindDirection) {

  uint16_t targetWind10000 = (uint16_t) (targetWindDirection * 10000); 
  
  byte byte0, byte1;
  byte0 = targetWind10000 & 0xff;
  byte1 = targetWind10000 >> 8;

  //41,ff,00,f8,03,01,3b,07,03,04,04,00,00
  
  N2kMsg.SetPGN(126208UL);
  N2kMsg.Priority=3;
  N2kMsg.Destination=PilotSourceAddress;
  N2kMsg.AddByte(1); // Field 1, 1 = Command Message, 2 = Acknowledge Message...
  N2kMsg.AddByte(0x41);
  N2kMsg.AddByte(0xff);
  N2kMsg.AddByte(0x00);
  N2kMsg.AddByte(0xf8);
  N2kMsg.AddByte(0x03);
  N2kMsg.AddByte(0x01);
  N2kMsg.AddByte(0x3b);
  N2kMsg.AddByte(0x07);
  N2kMsg.AddByte(0x03);
  N2kMsg.AddByte(0x04);
  N2kMsg.AddByte(0x04);
  N2kMsg.AddByte(byte0);
  N2kMsg.AddByte(byte1);
  
}


void RaymarinePilot::TurnToWaypointMode(tN2kMsg &N2kMsg){
 //"01,63,ff,00,f8,04,01,3b,07,03,04,04,81,01,05,ff,ff" 
  N2kMsg.SetPGN(126208UL);
  N2kMsg.Priority=3;
  N2kMsg.Destination=PilotSourceAddress;
  N2kMsg.AddByte(0x01); // Field 1, 1 = Command Message, 2 = Acknowledge Message...
  N2kMsg.AddByte(0x63);
  N2kMsg.AddByte(0xff);
  N2kMsg.AddByte(0x00);
  N2kMsg.AddByte(0xf8);
  N2kMsg.AddByte(0x04);
  N2kMsg.AddByte(0x01);
  N2kMsg.AddByte(0x3b);
  N2kMsg.AddByte(0x07);
  N2kMsg.AddByte(0x03);
  N2kMsg.AddByte(0x04);
  N2kMsg.AddByte(0x04);
  N2kMsg.AddByte(0x81);
  N2kMsg.AddByte(0x01);
  N2kMsg.AddByte(0x05);
  N2kMsg.AddByte(0xff);
  N2kMsg.AddByte(0xff);
}

void RaymarinePilot::TurnToWaypoint(tN2kMsg &N2kMsg){
  //00,00,ef,01,ff,ff,ff,ff,ff,ff,04,01,3b,07,03,04,04,6c,05,1a,50"
  
  N2kMsg.SetPGN(126208UL);
  N2kMsg.Priority=3;
  N2kMsg.Destination=PilotSourceAddress;
  N2kMsg.AddByte(0x00);
  N2kMsg.AddByte(0x00);
  N2kMsg.AddByte(0xef);
  N2kMsg.AddByte(0x01);
  N2kMsg.AddByte(0xff);
  N2kMsg.AddByte(0xff);
  N2kMsg.AddByte(0xff);
  N2kMsg.AddByte(0xff);
  N2kMsg.AddByte(0xff);
  N2kMsg.AddByte(0xff);
  N2kMsg.AddByte(0x04);
  N2kMsg.AddByte(0x01);
  N2kMsg.AddByte(0x3b);
  N2kMsg.AddByte(0x07);
  N2kMsg.AddByte(0x03);
  N2kMsg.AddByte(0x04);
  N2kMsg.AddByte(0x04);
  N2kMsg.AddByte(0x6c);
  N2kMsg.AddByte(0x05);
  N2kMsg.AddByte(0x1a);
  N2kMsg.AddByte(0x50);
}

void RaymarinePilot::KeyCommand(tN2kMsg &N2kMsg,uint16_t command){
  //const key_command = "3b,9f,f0,81,86,21,%s,%s,ff,ff,ff,ff,ff,c1,c2,cd,66,80,d3,42,b1,c8"

  byte commandByte0, commandByte1;
  commandByte0 = command >> 8;
  commandByte1 = command & 0xff;
  
  N2kMsg.SetPGN(126720UL);
  N2kMsg.Priority=7;
  N2kMsg.Destination=PilotSourceAddress;

  N2kMsg.AddByte(0x3b);
  N2kMsg.AddByte(0x9f);
  N2kMsg.AddByte(0xf0);
  N2kMsg.AddByte(0x81);
  N2kMsg.AddByte(0x86);
  N2kMsg.AddByte(0x21);
  //N2kMsg.Add2ByteUInt(command);
  N2kMsg.AddByte(commandByte0);
  N2kMsg.AddByte(commandByte1);
  N2kMsg.AddByte(0xff);
  N2kMsg.AddByte(0xff);
  N2kMsg.AddByte(0xff);
  N2kMsg.AddByte(0xff);
  N2kMsg.AddByte(0xff);
  N2kMsg.AddByte(0xc1);
  N2kMsg.AddByte(0xc2);
  N2kMsg.AddByte(0xcd);
  N2kMsg.AddByte(0x66);
  N2kMsg.AddByte(0x80);
  N2kMsg.AddByte(0xd3);
  N2kMsg.AddByte(0x42);
  N2kMsg.AddByte(0xb1);
  N2kMsg.AddByte(0xc8);
}
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

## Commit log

2020-07-15 add project files
    [NMEA2000_USB.brd]
2020-07-15 move board to separate folder
    [NMEA2000_USB.brd]
2021-06-29 fixed buzzer fixed remote input codes added debug outputs
    [EvoPilotremote.ino]
2021-06-29 Added pcb & 3d models
    [Autopilot_remote_receiver.brd, Autopilot_remote_sender.brd, Back.stl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]
2023-01-24 Add schematic Update board
    [Autopilot_remote_receiver.brd, Autopilot_remote_receiver.sch, Autopilot_remote_sender.brd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]
2023-01-24 Add board png
2023-01-25 Add schematic png
2025-01-13 Add gerber files
    [Autopilot_remote_receiver.brd, Autopilot_remote_sender.brd]
2025-01-13 Add watchdog timer
